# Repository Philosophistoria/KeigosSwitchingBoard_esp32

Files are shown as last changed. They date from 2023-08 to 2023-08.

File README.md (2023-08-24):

# KeigosSwitchingBoard_esp32
Keigo's photo MOSFET switching board's hardware and software

PC side program: https://github.com/Philosophistoria/KeigosSwitchingBoard_python/tree/main

| pin (GPIO) | name on board | name in the program |
| --- | --- | --- |
| 32 | DI | SER |
| 33 | RC | CLK (clock of shift resisters) |
| 25 | CL | CLR |
| 26 | CK | RCK (Clock of latches) |

components for switching cirtuit
- photo relay: [TLP176GA](https://www.mouser.jp/ProductDetail/Toshiba/TLP176GAF?qs=L%2FgSpqKJZEvJJ3hcHMwEJw%3D%3D)
- shift resister: [74HC595](https://www.ti.com/product/SN74HC595)

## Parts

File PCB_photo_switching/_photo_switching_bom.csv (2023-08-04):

Comment | Designator | Footprint | LCSC
0.1u | C1,C2,C3,C4 | Capacitor_SMD:C_0201_0603Metric_Pad0.64x0.40mm_HandSolder | C14663
signals | J1 | Connector_PinSocket_2.54mm:PinSocket_1x07_P2.54mm_Vertical
output | J2 | Connector_PinSocket_2.54mm:PinSocket_2x08_P2.54mm_Vertical
source | J3 | Connector_PinSocket_2.54mm:PinSocket_1x02_P2.54mm_Vertical
470 | R1,R2,R3,R4,R5,R6,R7,R8,R9,R10,R11,R12,R13,R14,R15,R16,R17,R18,R19,R20,R21,R22,R23,R24,R25,R26,R27,R28,R29,R30,R31,R32 | Resistor_SMD:R_0201_0603Metric_Pad0.64x0.40mm_HandSolder | C23179
74HC595 | U1,U10,U19,U20 | Package_SO:TSSOP-16_4.4x5mm_P0.65mm | C273642
TLP176GA | U2,U3,U4,U5,U6,U7,U8,U9,U11,U12,U13,U14,U15,U16,U17,U18,U21,U22,U23,U24,U25,U26,U27,U28,U29,U30,U31,U32,U33,U34,U35,U36 | keigo_custom_footprint:TLP176GA | C516859

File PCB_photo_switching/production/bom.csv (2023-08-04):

Designator | Footprint | Quantity | Value | LCSC Part #
C1, C2, C3, C4 | C_0201_0603Metric_Pad0.64x0.40mm_HandSolder | 4 | 0.1u | C14663
J1 | PinSocket_1x07_P2.54mm_Vertical | 1 | signals
J2 | PinSocket_2x08_P2.54mm_Vertical | 1 | output
J3 | PinSocket_1x02_P2.54mm_Vertical | 1 | source
R1, R10, R11, R12, R13, R14, R15, R16, R17, R18, R19, R2, R20, R21, R22, R23, R24, R25, R26, R27, R28, R29, R3, R30, R31, R32, R4, R5, R6, R7, R8, R9 | R_0201_0603Metric_Pad0.64x0.40mm_HandSolder | 32 | 470 | C23179
U1, U10, U19, U20 | TSSOP-16_4.4x5mm_P0.65mm | 4 | 74HC595 | C273642
U11, U12, U13, U14, U15, U16, U17, U18, U2, U21, U22, U23, U24, U25, U26, U27, U28, U29, U3, U30, U31, U32, U33, U34, U35, U36, U4, U5, U6, U7, U8, U9 | TLP176GA | 32 | TLP176GA | C516859

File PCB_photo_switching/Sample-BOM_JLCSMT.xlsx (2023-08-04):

Comment | Designator | Footprint | JLCPCB Part #（optional）
100uF | C1 | CAP-SMD_L3.5-W2.8 | C16133
15K | R5,R6 | R0603 | C22809
DC-005-20A_C136744 | DC1 | DC-IN-TH_DC-005-20A | C136744
Header-Female-2.54_1x8 | P2,P3 | HDR-TH_8P-P2.54-V | C27438
K2-1102DP-C4SW-04 | SW1 | KEY-TH_4P-L6.0-W6.0-P4.50-LS6.5 | C110153
ATMEGA328P-PU | U1 | DIP-28_L34.6-W7.3-P2.54-LS10.2-BL | C33901
670688000 | USB1 | USB-B-TH_67068-8000 | C114097

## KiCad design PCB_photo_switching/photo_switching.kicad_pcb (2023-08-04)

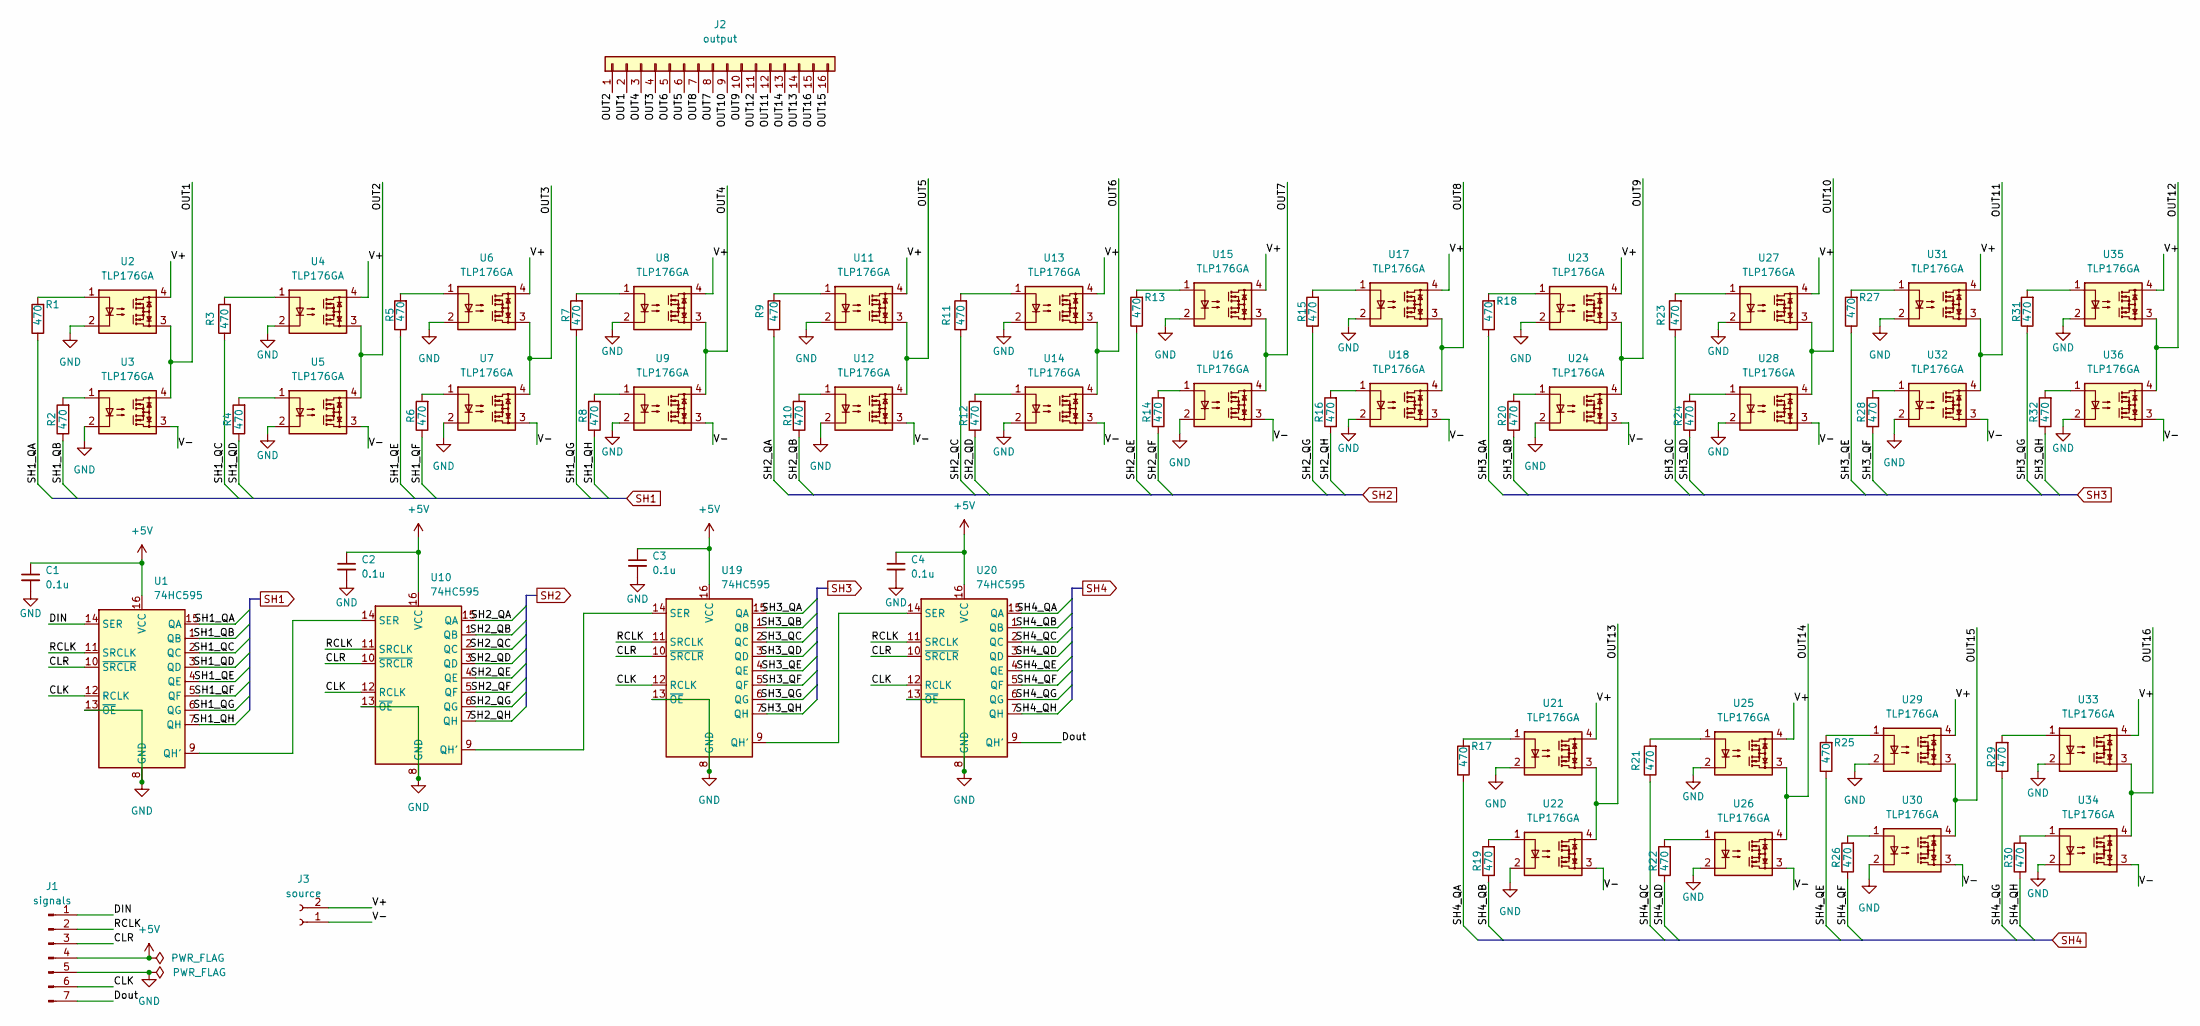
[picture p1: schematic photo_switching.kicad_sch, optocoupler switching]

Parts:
C1, C2, C3, C4: 0.1u; C_0603_1608Metric
J1: signals; PinSocket_1x07_P2.54mm_Vertical
J2: output; PinSocket_2x08_P2.54mm_Vertical
J3: source; PinSocket_1x02_P2.54mm_Vertical
R1, R2, R3, R4, R5, R6, R7, R8, R9, R10, R11, R12, R13, R14, R15, R16, R17, R18, R19, R20, R21, R22, R23, R24, R25, R26, R27, R28, R29, R30, R31, R32: 470; R_0603_1608Metric
U1, U10, U19, U20: 74HC595; TSSOP-16_4.4x5mm_P0.65mm; LCSC C273642
U2: TLP176GA; LCSC C516859
U3, U4, U5, U6, U7, U8, U9, U11, U12, U13, U14, U15, U16, U17, U18, U21, U22, U23, U24, U25, U26, U27, U28, U29, U30, U31, U32, U33, U34, U35, U36: TLP176GA

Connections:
+5V: C1.1, C2.1, C3.1, C4.1, J1.4, U1.16 (VCC), U10.16 (VCC), U19.16 (VCC), U20.16 (VCC)
/CLK: J1.6, U1.12 (RCLK), U10.12 (RCLK), U19.12 (RCLK), U20.12 (RCLK)
/CLR: J1.3, U1.10 (~SRCLR), U10.10 (~SRCLR), U19.10 (~SRCLR), U20.10 (~SRCLR)
/DIN: J1.1, U1.14 (SER)
/Dout: J1.7, U20.9 (QH')
/OUT1: J2.2, U2.3, U3.4
/OUT2: J2.1, U4.3, U5.4
/OUT3: J2.4, U6.3, U7.4
/OUT4: J2.3, U8.3, U9.4
/OUT5: J2.6, U11.3, U12.4
/OUT6: J2.5, U13.3, U14.4
/OUT7: J2.8, U15.3, U16.4
/OUT8: J2.7, U17.3, U18.4
/OUT9: J2.10, U23.3, U24.4
/OUT10: J2.9, U27.3, U28.4
/OUT11: J2.12, U31.3, U32.4
/OUT12: J2.11, U35.3, U36.4
/OUT13: J2.14, U21.3, U22.4
/OUT14: J2.13, U25.3, U26.4
/OUT15: J2.16, U29.3, U30.4
/OUT16: J2.15, U33.3, U34.4
/RCLK: J1.2, U1.11 (SRCLK), U10.11 (SRCLK), U19.11 (SRCLK), U20.11 (SRCLK)
/SH1_QA: R1.1, U1.15 (QA)
/SH1_QB: R2.1, U1.1 (QB)
/SH1_QC: R3.1, U1.2 (QC)
/SH1_QD: R4.1, U1.3 (QD)
/SH1_QE: R5.1, U1.4 (QE)
/SH1_QF: R6.1, U1.5 (QF)
/SH1_QG: R7.1, U1.6 (QG)
/SH1_QH: R8.1, U1.7 (QH)
/SH2_QA: R9.1, U10.15 (QA)
/SH2_QB: R10.1, U10.1 (QB)
/SH2_QC: R11.1, U10.2 (QC)
/SH2_QD: R12.1, U10.3 (QD)
/SH2_QE: R13.1, U10.4 (QE)
/SH2_QF: R14.1, U10.5 (QF)
/SH2_QG: R15.1, U10.6 (QG)
/SH2_QH: R16.1, U10.7 (QH)
/SH3_QA: R18.1, U19.15 (QA)
/SH3_QB: R20.1, U19.1 (QB)
/SH3_QC: R23.1, U19.2 (QC)
/SH3_QD: R24.1, U19.3 (QD)
/SH3_QE: R27.1, U19.4 (QE)
/SH3_QF: R28.1, U19.5 (QF)
/SH3_QG: R31.1, U19.6 (QG)
/SH3_QH: R32.1, U19.7 (QH)
/SH4_QA: R17.1, U20.15 (QA)
/SH4_QB: R19.1, U20.1 (QB)
/SH4_QC: R21.1, U20.2 (QC)
/SH4_QD: R22.1, U20.3 (QD)
/SH4_QE: R25.1, U20.4 (QE)
/SH4_QF: R26.1, U20.5 (QF)
/SH4_QG: R29.1, U20.6 (QG)
/SH4_QH: R30.1, U20.7 (QH)
/V+: J3.2, U2.4, U4.4, U6.4, U8.4, U11.4, U13.4, U15.4, U17.4, U21.4, U23.4, U25.4, U27.4, U29.4, U31.4, U33.4, U35.4
/V-: J3.1, U3.3, U5.3, U7.3, U9.3, U12.3, U14.3, U16.3, U18.3, U22.3, U24.3, U26.3, U28.3, U30.3, U32.3, U34.3, U36.3
GND: C1.2, C2.2, C3.2, C4.2, J1.5, U1.8 (GND), U1.13 (~OE), U2.2, U3.2, U4.2, U5.2, U6.2, U7.2, U8.2, U9.2, U10.8 (GND), U10.13 (~OE), U11.2, U12.2, U13.2, U14.2, U15.2, U16.2, U17.2, U18.2, U19.8 (GND), U19.13 (~OE), U20.8 (GND), U20.13 (~OE), U21.2, U22.2, U23.2, U24.2, U25.2, U26.2, U27.2, U28.2, U29.2, U30.2, U31.2, U32.2, U33.2, U34.2, U35.2, U36.2
unnamed: R1.2, U2.1
unnamed: R2.2, U3.1
unnamed: R3.2, U4.1
unnamed: R4.2, U5.1
unnamed: R5.2, U6.1
unnamed: R6.2, U7.1
unnamed: R7.2, U8.1
unnamed: R8.2, U9.1
unnamed: R9.2, U11.1
unnamed: R10.2, U12.1
unnamed: R11.2, U13.1
unnamed: R12.2, U14.1
unnamed: R13.2, U15.1
unnamed: R14.2, U16.1
unnamed: R15.2, U17.1
unnamed: R16.2, U18.1
unnamed: R17.2, U21.1
unnamed: R18.2, U23.1
unnamed: R19.2, U22.1
unnamed: R20.2, U24.1
unnamed: R21.2, U25.1
unnamed: R22.2, U26.1
unnamed: R23.2, U27.1
unnamed: R24.2, U28.1
unnamed: R25.2, U29.1
unnamed: R26.2, U30.1
unnamed: R27.2, U31.1
unnamed: R28.2, U32.1
unnamed: R29.2, U33.1
unnamed: R30.2, U34.1
unnamed: R31.2, U35.1
unnamed: R32.2, U36.1
unnamed: U1.9 (QH'), U10.14 (SER)
unnamed: U10.9 (QH'), U19.14 (SER)
unnamed: U19.9 (QH'), U20.14 (SER)

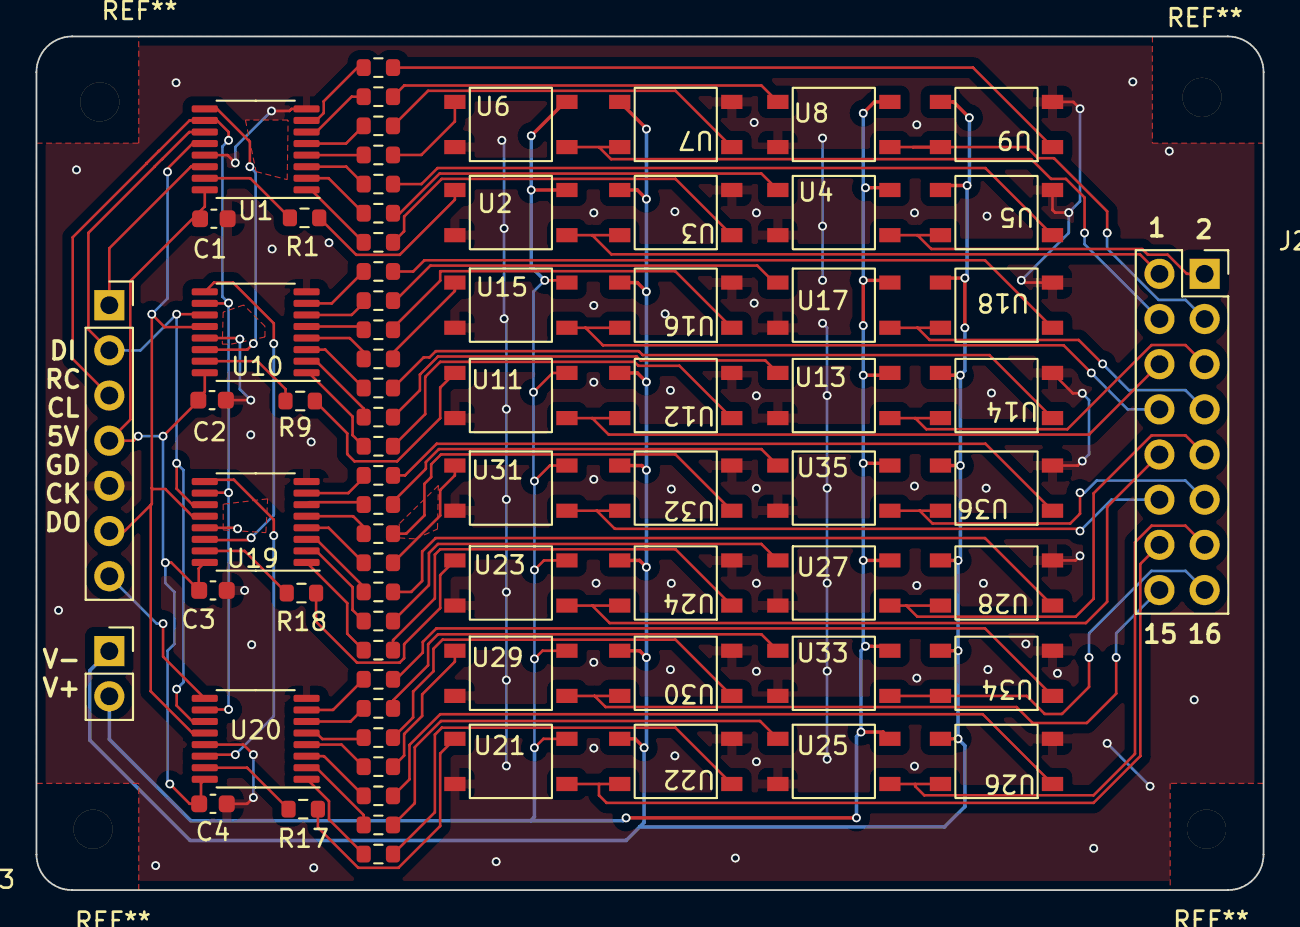
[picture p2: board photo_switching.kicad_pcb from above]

Board: 2 copper layers, 69.0 x 48.0 mm, 75 parts (0 on the bottom side), 92 nets.

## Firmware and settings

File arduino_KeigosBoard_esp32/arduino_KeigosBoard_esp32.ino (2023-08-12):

// ----
// esp32 devkit c
// ---

// headers
enum {
    REQUEST_CHANGE_STATE = 0xff,
    REQUEST_CHECK_STATE = 0xfe,
    REQUEST_CHANGE_ECHO_MODE = 0xfd
};
const int NUM_CH_USED = 12;

// for shift registers (optocoupler switching)
const int SR_SER    = 32;   // Keigo's = SER (DI)
const int SR_CLK    = 33;   // on board, it is written RCK but it's shift register's clk //26;  // Keigo's = 26
const int SR_CLR    = 25;   // Keigo's = RCLK (RC)
const int SR_RCLK   = 26;   // on board, it is written CK but it's actually a latch's clk //33; // Keigo's = CLK (CK)
const int SR_OE     = 27;   // not used

const int STATE_OPEN = 0;
const int STATE_GND = 1;
const int STATE_HIGH = 2;

// change this when you changed the number of boards!!
const int board_num = 1;
const int channel_num = 16;
const int register_num = (channel_num * 2) * board_num;
int register_state[register_num] = {0};
int channel_state[channel_num] = {STATE_OPEN};
enum {
    REACT_ON_EVERY_REQUEST = 0,
    ECHO_ONLY_ON_ECHO_REQUEST = 1,
    NO_ECHO = 2
};
int echo_mode = NO_ECHO;
// -----

// ------ electrical stimulation -----
void set_all_channel()
{
    digitalWrite(SR_CLK, LOW);
    digitalWrite(SR_RCLK, LOW);

    for (int i = channel_num - 1; i >= 0 ; i--)
    {
        if (channel_state[i] == STATE_OPEN)
        {
            // LOW
            digitalWrite(SR_SER, LOW);
            digitalWrite(SR_CLK, HIGH);
            digitalWrite(SR_CLK, LOW);
            // LOW
            digitalWrite(SR_SER, LOW);
            digitalWrite(SR_CLK, HIGH);
            digitalWrite(SR_CLK, LOW);
        }
        else if (channel_state[i] == STATE_HIGH)
        {
            // LOW
            digitalWrite(SR_SER, LOW);
            digitalWrite(SR_CLK, HIGH);
            digitalWrite(SR_CLK, LOW);
            // HIGH
            digitalWrite(SR_SER, HIGH);
            digitalWrite(SR_CLK, HIGH);
            digitalWrite(SR_CLK, LOW);
        }
        else if (channel_state[i] == STATE_GND)
        {
            // HIGH
            digitalWrite(SR_SER, HIGH);
            digitalWrite(SR_CLK, HIGH);
            digitalWrite(SR_CLK, LOW);
            // LOW
            digitalWrite(SR_SER, LOW);
            digitalWrite(SR_CLK, HIGH);
            digitalWrite(SR_CLK, LOW);
        }
    }

    digitalWrite(SR_SER, LOW);
    digitalWrite(SR_RCLK, HIGH);
    digitalWrite(SR_RCLK, LOW);
}

// ------

void setup()
{
    // --- for shift registers
    pinMode(SR_SER, OUTPUT);
    pinMode(SR_CLK, OUTPUT);
    pinMode(SR_RCLK, OUTPUT);
    pinMode(SR_CLR, OUTPUT);
    pinMode(SR_OE, OUTPUT);
    digitalWrite(SR_OE, LOW);
    digitalWrite(SR_CLR, HIGH);

    for (int i = 0; i < channel_num; i++)
    {
        channel_state[i] = STATE_OPEN;
    }
    set_all_channel();

    //  Serial.begin(921600);
    Serial.begin(1500000);
}

void loop()
{
    static int header = 0;
    if (Serial.available()) {
        header = Serial.read();
        if (echo_mode == REACT_ON_EVERY_REQUEST) {
            Serial.print("ECHO Header: ");
            Serial.print(header);
            Serial.print("\n");
        }
        if (header == REQUEST_CHANGE_ECHO_MODE)
        {
            if (Serial.available())
            {
                echo_mode = Serial.read();
            }
            if (echo_mode != NO_ECHO)
            {
                Serial.print("Echo mode has been changed to: ");
                Serial.print(echo_mode);
                Serial.print("\n");
            }
        }
        else if (header == REQUEST_CHECK_STATE)
        {
            Serial.print("Channel status: ");
            for (int i = 0; i < channel_num; i++) {
                Serial.print(channel_state[i]);
                Serial.print(" ");
            }
            Serial.print("\n");
        }
        else if (header == REQUEST_CHANGE_STATE)
        {
            if (Serial.available() >= NUM_CH_USED)
            {
                byte state = 0;
                for (int i = 0; i < channel_num; i++)
                {
                    channel_state[i] = STATE_OPEN;
                }
                for (int i = 0; i < NUM_CH_USED; i++)
                {
                    state = Serial.read();
                    if (state < 0 || 2 < state)
                    {
                        // out of range. something went wrong
                        continue;
                    }
                    channel_state[i] = state;
                }
                set_all_channel();

                if (echo_mode == REACT_ON_EVERY_REQUEST)
                {
                    Serial.print("all channels has been set\n");
                }
            }
            else {
                if (echo_mode == REACT_ON_EVERY_REQUEST)
                {
                    Serial.print("ERROR: The received data size was small\n");
                }

            }
        }
    }
}

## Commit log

2023-07-06 Just changed pin numbers order from Keigo's
2023-08-03 Fixed bug such like the reverse order of insertion data to shift resiter and reverse connection of RCK and CLK
2023-08-04 added PCB data
    [Sample-BOM_JLCSMT.xlsx, _photo_switching_bom.csv, bom.csv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]
2023-08-12 Update comment in arduino_KeigosBoard_esp32.ino
